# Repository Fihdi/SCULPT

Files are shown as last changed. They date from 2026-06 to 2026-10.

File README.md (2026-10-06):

# 8hp ADSR Module

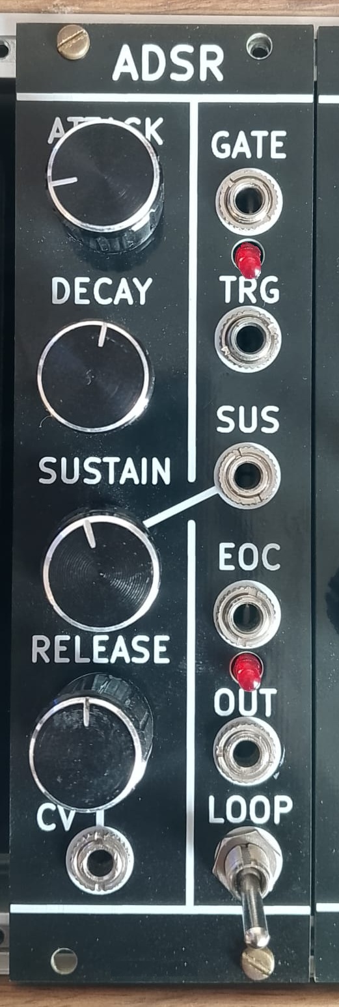
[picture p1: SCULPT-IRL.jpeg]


SCULPT is a 4 stage envelope generator with Attack, Decay, Sustain and Release control. Additionally, the Sustain level and the Release time can be voltage controlled. Engaging the LOOP switch connects the End-of-cycle (EOC) Gate back into the GATE input, turning the module into an LFO with variable rise and fall times.

While the module is in the sustain phase, an external CV source can be used to modulate the sustain level. The DECAY knob changes the slew rate of the SUS input during this stage.

A gate signal to the TRG input sets the module to the attack stage. 

By using a random voltage generator, the EOC output, together with the Release-CV input, can be used to create so-called "Krell patches".

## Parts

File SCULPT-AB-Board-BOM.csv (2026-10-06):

Reference | Value | Footprint | Qty
C1,C3 | 10n | Capacitor_SMD:C_0805_2012Metric | 2
C2,C7,C8 | 1u | Capacitor_SMD:C_0805_2012Metric | 3
C4,C5,C6 | 100n | Capacitor_SMD:C_0805_2012Metric | 3
C9 | ext | Capacitor_THT:C_Radial_D6.3mm_H11.0mm_P2.50mm | 1
D1,D2,D3,D4,D6,D7,D8,D9,D11,D12,D13,D14,D15,D16 | IN4148 | Diode_SMD:D_SOD-323_HandSoldering | 14
D5,D10 | LED | LED_THT:LED_D3.0mm | 2
J4,J5,J6,J7,J8,J9 | AudioJack2 | Library:MonoTRS | 6
J15 | Conn_02x05_Odd_Even | Connector_IDC:IDC-Header_2x05_P2.54mm_Vertical | 1
Q3,Q4,Q5 | BC847 | Package_TO_SOT_SMD:SOT-23 | 3
R1,R4,R16 | 47k | Resistor_SMD:R_0805_2012Metric | 3
R2,R10,R14,R19,R21,R29,R30,R32 | 100k | Resistor_SMD:R_0805_2012Metric | 8
R3,R7,R8,R13,R15,R17,R18,R23,R27 | 10k | Resistor_SMD:R_0805_2012Metric | 9
R5 | 100R | Resistor_SMD:R_0805_2012Metric | 1
R12,R20 | 1k | Resistor_SMD:R_0805_2012Metric | 2
R22 | 33k | Resistor_SMD:R_0805_2012Metric | 1
R24 | 2k2 | Resistor_SMD:R_0805_2012Metric | 1
R25 | 4k7 | Resistor_SMD:R_0805_2012Metric | 1
RV1,RV2,RV3,RV4 | 100k | Potentiometer_THT:Potentiometer_Alpha_RD901F-40-00D_Single_Vertical | 4
SW1 | SW_SPDT | Library:Switch | 1
U1 | TL074 | Package_SO:SOIC-14_3.9x8.7mm_P1.27mm | 1
U2 | TL072 | Package_SO:SOIC-8_3.9x4.9mm_P1.27mm | 1
U4 | 4066 | Package_SO:SOIC-14_3.9x8.7mm_P1.27mm | 1

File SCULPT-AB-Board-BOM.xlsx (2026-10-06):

 |  |  | SCULPT-AB-Board BOM
Item # | *Designator | *Qty | Manufacturer | *Mfg Part # | Description / Value | *Package/Footprint | Type | Your Instructions / Notes
1 | C1,C3 | 2 |  | C1710 | 10n | Capacitor_SMD:C_0805_2012Metric
2 | C2,C7,C8 | 3 |  | C28323 | 1u | Capacitor_SMD:C_0805_2012Metric
3 | C4,C5,C6 | 3 |  | C49678 | 100n | Capacitor_SMD:C_0805_2012Metric
4 | C9 | 1 |  |  | ext | Capacitor_THT:C_Radial_D6.3mm_H11.0mm_P2.50mm |  | DNP
5 | D1,D2,D3,D4,D6,D7,D8,D9,D11,D12,D13,D14,D15,D16 | 14 |  | C917117 | 1N4148 | Diode_SMD:D_SOD-323_HandSoldering
6 | D5,D10 | 2 |  |  | LED | LED_THT:LED_D3.0mm |  | DNP
7 | J4,J5,J6,J7,J8,J9 | 6 |  |  | AudioJack2 | Library:MonoTRS |  | DNP
8 | J15 | 1 |  |  | Conn_02x05_Odd_Even | Connector_IDC:IDC-Header_2x05_P2.54mm_Vertical |  | DNP
9 | Q3,Q4,Q5 | 3 |  | C475630 | BC847 | Package_TO_SOT_SMD:SOT-23
10 | R1,R4,R16 | 3 |  | C2930202 | 47k | Resistor_SMD:R_0805_2012Metric
11 | R2,R10,R14,R19,R21,R29,R30,R32 | 8 |  | C2907217 | 100k | Resistor_SMD:R_0805_2012Metric
12 | R3,R7,R8,R13,R15,R17,R18,R23,R27 | 9 |  | C17414 | 10k | Resistor_SMD:R_0805_2012Metric
13 | R5 | 1 |  | C17408 (https://www.lcsc.com/de/product-detail/C17408.html?s_z=n_q_t_100%2520ohm%25200805) | 100R | Resistor_SMD:R_0805_2012Metric
14 | R12,R20 | 2 |  | C95781 | 1k | Resistor_SMD:R_0805_2012Metric
15 | R22 | 1 |  | C2933415 | 33k | Resistor_SMD:R_0805_2012Metric
16 | R24 | 1 |  | C114561 | 2k2 | Resistor_SMD:R_0805_2012Metric
17 | R25 | 1 |  | C2907326 | 4k7 | Resistor_SMD:R_0805_2012Metric
18 | RV1,RV2,RV3,RV4 | 4 |  |  | 100k | Potentiometer_THT:Potentiometer_Alpha_RD901F-40-00D_Single_Vertical |  | DNP
19 | SW1 | 1 |  |  | SW_SPDT | Library:Switch |  | DNP
20 | U1 | 1 |  | C12594 | TL074 | Package_SO:SOIC-14_3.9x8.7mm_P1.27mm
21 | U2 | 1 |  | C67473 | TL072 | Package_SO:SOIC-8_3.9x4.9mm_P1.27mm
22 | U4 | 1 |  | C54755 | 4066 | Package_SO:SOIC-14_3.9x8.7mm_P1.27mm
Need a quick and accurante quote? Need an efficient production? Please read SMT Ordering Necessary Files & Info in 1 minute. Thank you very much!
Click for Instructions on How to Create a BOM (https://www.pcbway.com/blog/PCB_Assembly/How_to_Build_a_BOM__Bill_Of_Materials_.html)

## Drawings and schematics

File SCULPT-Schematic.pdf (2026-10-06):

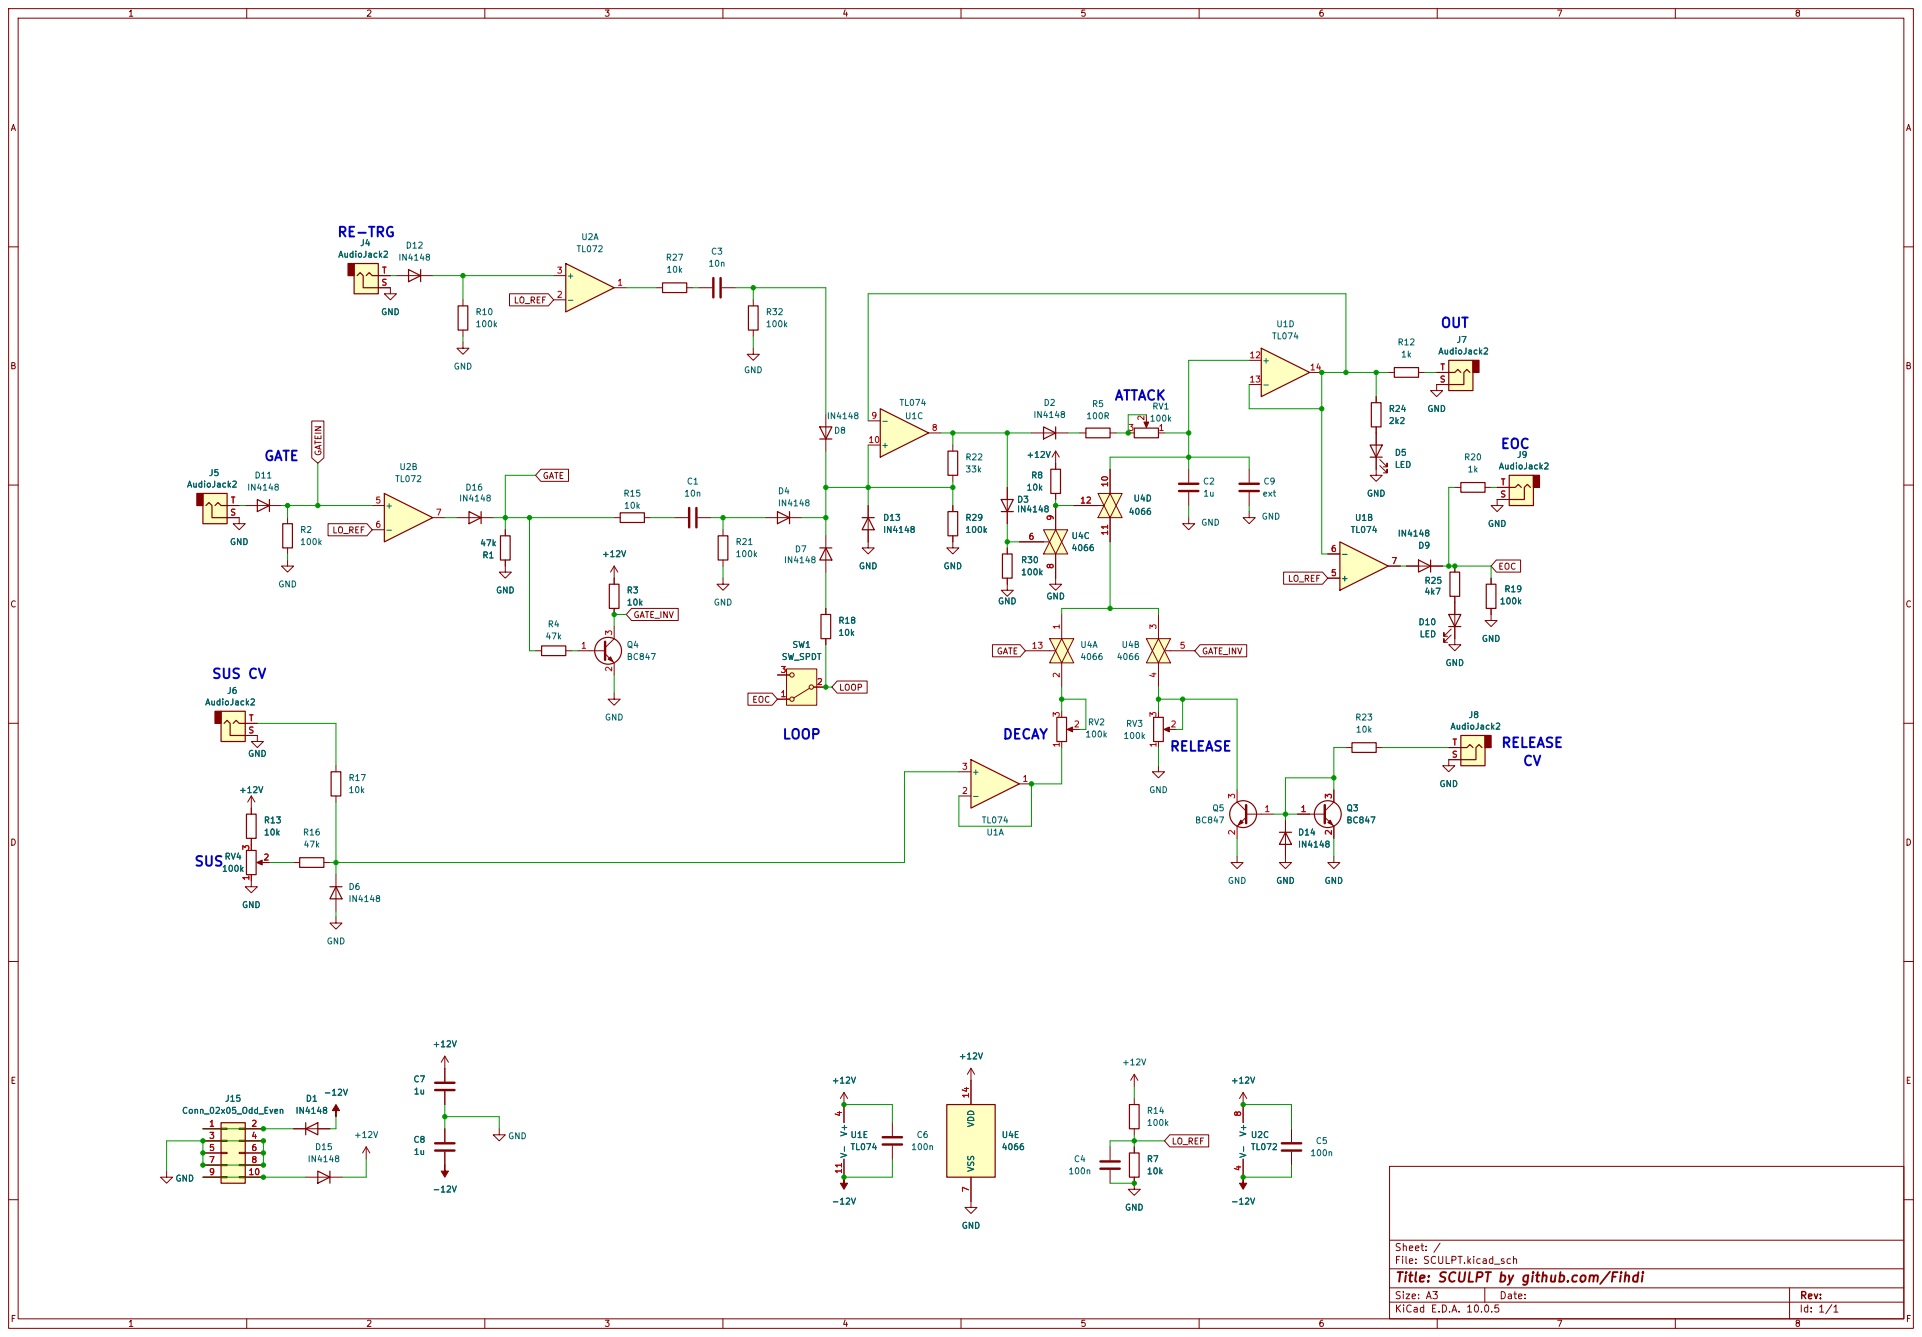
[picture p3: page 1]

5 5 | 6 6
7 7 | 8 8

Sheet: /
File: SCULPT.kicad_sch
Title: SCULPT by github.com/Fihdi

Size: A3 | Rev: | F Date:
KiCad E.D.A. 10.0.5 | Id: 1/1

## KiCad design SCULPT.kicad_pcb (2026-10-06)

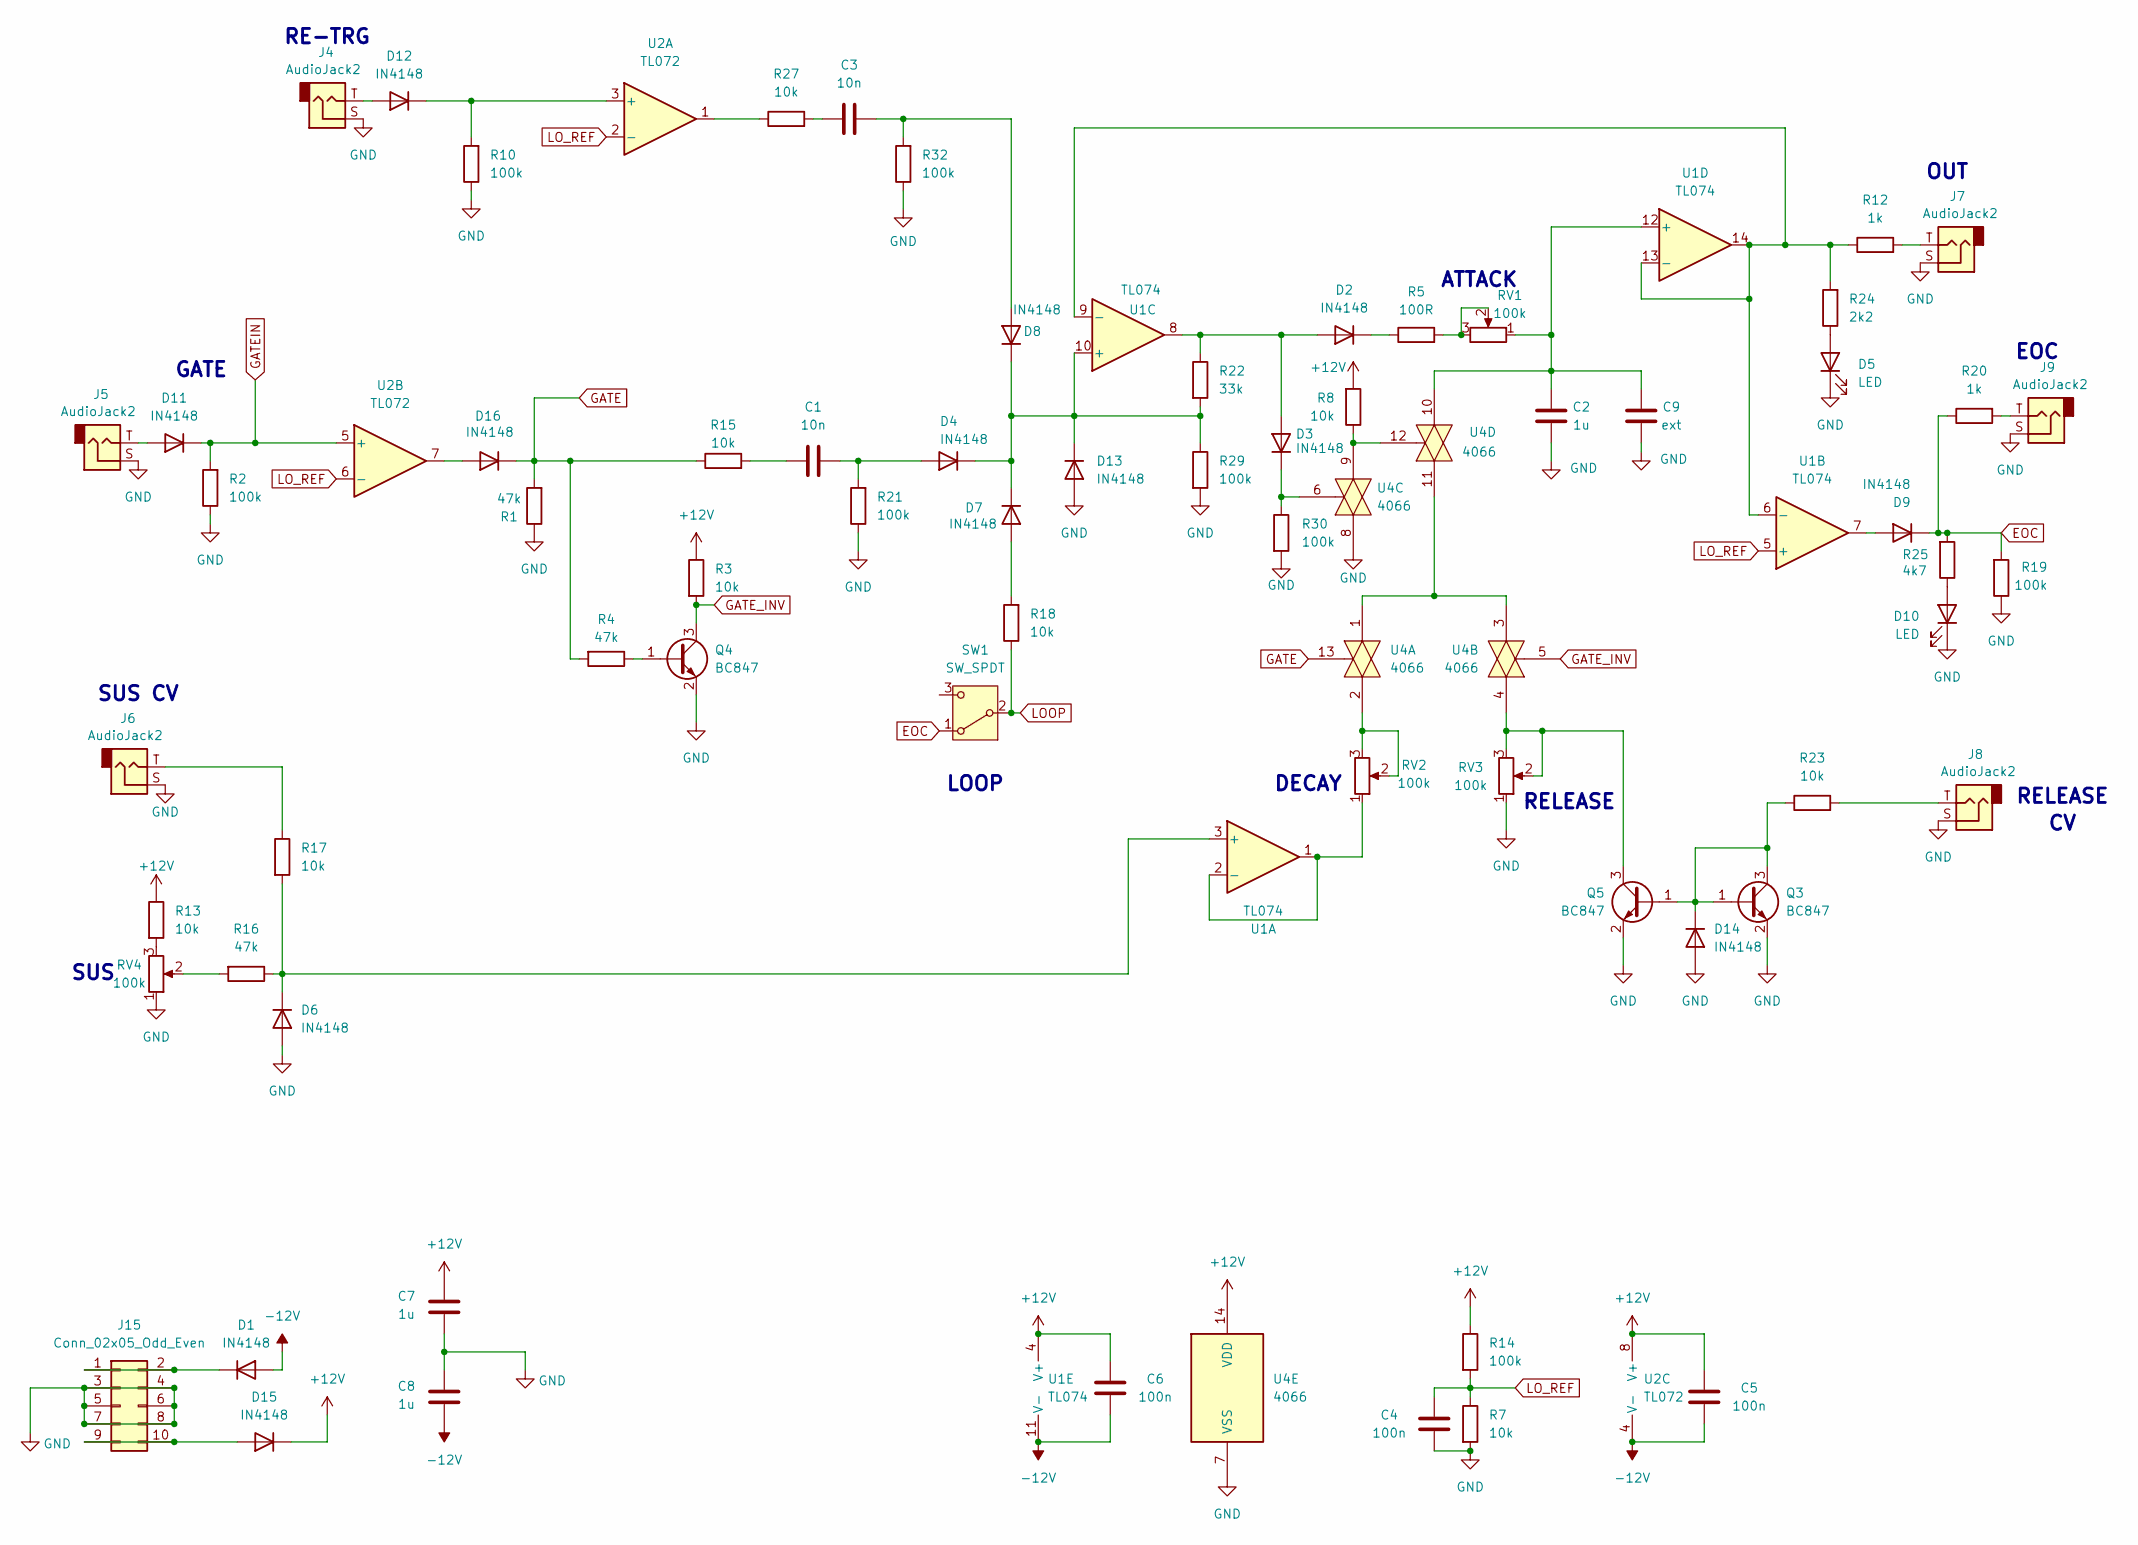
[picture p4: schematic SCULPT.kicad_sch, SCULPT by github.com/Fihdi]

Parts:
C1, C3: 10n; C_0805_2012Metric
C2, C7, C8: 1u; C_0805_2012Metric
C4, C5, C6: 100n; C_0805_2012Metric
C9: ext; C_Radial_D6.3mm_H11.0mm_P2.50mm
D1, D2, D3, D4, D6, D7, D8, D9, D11, D12, D13, D14, D15, D16: IN4148; D_SOD-323_HandSoldering
D5, D10: LED; LED_D3.0mm
J4, J5, J6, J7, J8, J9: AudioJack2; MonoTRS
J15: Conn_02x05_Odd_Even; IDC-Header_2x05_P2.54mm_Vertical
Q3, Q4, Q5: BC847; SOT-23
R1, R4, R16: 47k; R_0805_2012Metric
R2, R10, R14, R19, R21, R29, R30, R32: 100k; R_0805_2012Metric
R3, R7, R8, R13, R15, R17, R18, R23, R27: 10k; R_0805_2012Metric
R5: 100R; R_0805_2012Metric
R12, R20: 1k; R_0805_2012Metric
R22: 33k; R_0805_2012Metric
R24: 2k2; R_0805_2012Metric
R25: 4k7; R_0805_2012Metric
RV1, RV2, RV3, RV4: 100k; Potentiometer_Alpha_RD901F-40-00D_Single_Vertical
SW1: SW_SPDT; Switch
U1: TL074; SOIC-14_3.9x8.7mm_P1.27mm
U2: TL072; SOIC-8_3.9x4.9mm_P1.27mm
U4: 4066; SOIC-14_3.9x8.7mm_P1.27mm

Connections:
+12V: C5.1, C6.1, C7.1, D15.1 (K), R3.1, R8.2, R13.1, R14.1, U1.4 (V+), U2.8 (V+), U4.14 (VDD)
-12V: C5.2, C6.2, C8.2, D1.2 (A), U1.11 (V-), U2.4 (V-)
EOC: D9.1 (K), R19.2, R20.1, R25.2, SW1.1 (A)
GATE: D16.1 (K), R1.2, R4.2, R15.1, U4.13
GATEIN: D11.1 (K), R2.2, U2.5 (+)
GATE_INV: Q4.3 (C), R3.2, U4.5
GND: C2.1, C4.1, C7.2, C8.1, C9.1, D5.1 (K), D6.2 (A), D10.1 (K), D13.2 (A), D14.2 (A), J4.S, J5.S, J6.S, J7.S, J8.S, J9.S, J15.3, J15.4, J15.5, J15.6, J15.7, J15.8, Q3.2 (E), Q4.2 (E), Q5.2 (E), R1.1, R2.1, R7.2, R10.1, R19.1, R21.1, R29.2, R30.2, R32.1, RV3.1, RV4.1, U4.7 (VSS), U4.8
LOOP: R18.1, SW1.2 (B)
LO_REF: C4.2, R7.1, R14.2, U1.5 (+), U2.2 (-), U2.6 (-)
unnamed: C1.1, R15.2
unnamed: C3.1, R27.2
unnamed: D1.1 (K), J15.1, J15.2
unnamed: D2.2 (A), D3.2 (A), R22.1, U1.8
unnamed: D2.1 (K), R5.1
unnamed: D3.1 (K), R30.1, U4.6
unnamed: C1.2, D4.2 (A), R21.2
unnamed: D5.2 (A), R24.1
unnamed: D6.1 (K), R16.1, R17.2, U1.3 (+)
unnamed: D7.2 (A), R18.2
unnamed: C3.2, D8.2 (A), R32.2
unnamed: D9.2 (A), U1.7
unnamed: D10.2 (A), R25.1
unnamed: D11.2 (A), J5.T
unnamed: D12.2 (A), J4.T
unnamed: D12.1 (K), R10.2, U2.3 (+)
unnamed: D4.1 (K), D7.1 (K), D8.1 (K), D13.1 (K), R22.2, R29.1, U1.10 (+)
unnamed: D14.1 (K), Q3.1 (B), Q3.3 (C), Q5.1 (B), R23.1
unnamed: D15.2 (A), J15.9, J15.10
unnamed: D16.2 (A), U2.7
unnamed: J6.T, R17.1
unnamed: J7.T, R12.2
unnamed: J8.T, R23.2
unnamed: J9.T, R20.2
unnamed: Q4.1 (B), R4.1
unnamed: Q5.3 (C), RV3.2, RV3.3, U4.4
unnamed: R5.2, RV1.2, RV1.3
unnamed: R8.1, U4.9, U4.12
unnamed: R13.2, RV4.3
unnamed: R16.2, RV4.2
unnamed: R27.1, U2.1
unnamed: RV2.2, RV2.3, U4.2
unnamed: RV2.1, U1.1, U1.2 (-)
unnamed: R12.1, R24.2, U1.6 (-), U1.9 (-), U1.13 (-), U1.14
unnamed: C2.2, C9.2, RV1.1, U1.12 (+), U4.10
unnamed: U4.1, U4.3, U4.11

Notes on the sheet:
ATTACK
DECAY
LOOP
RELEASE
RE-TRG
SUS
GATE
SUS CV
EOC
OUT

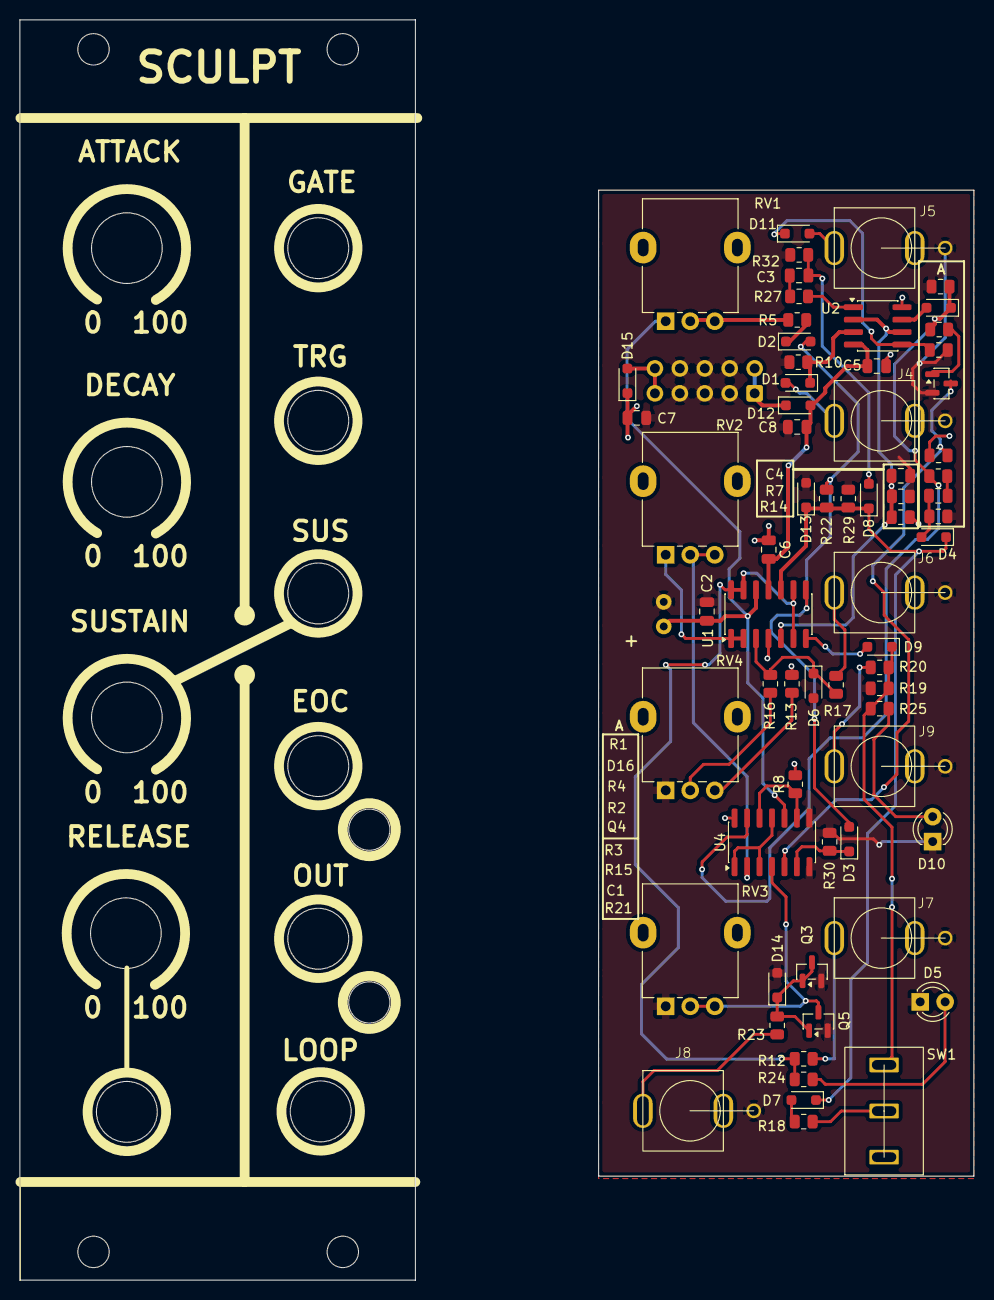
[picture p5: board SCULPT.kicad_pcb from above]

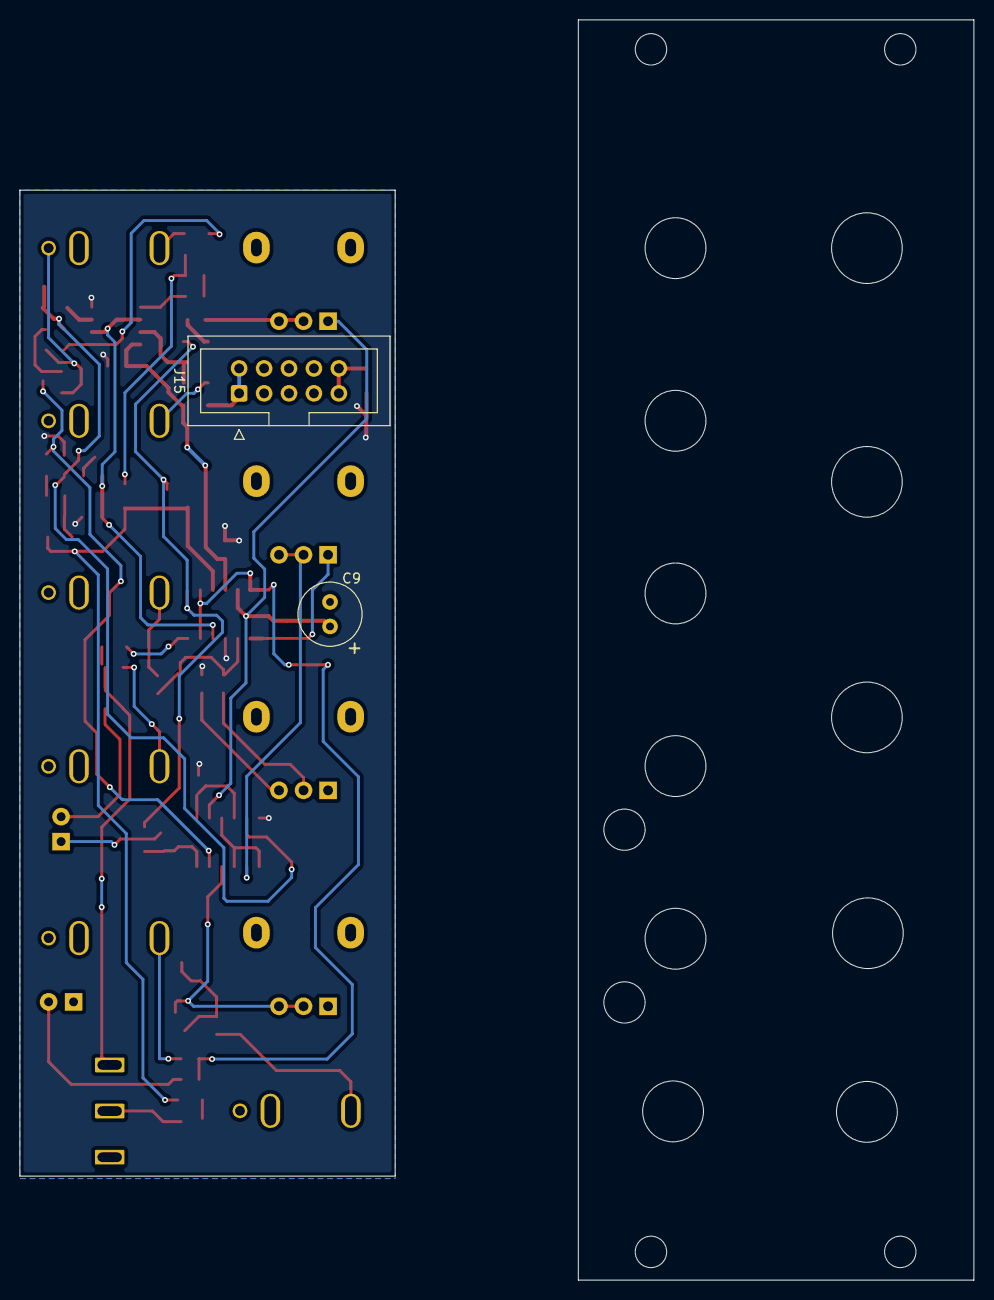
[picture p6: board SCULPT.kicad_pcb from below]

Board: 2 copper layers, 38.2 x 100.5 mm, 69 parts (2 on the bottom side), 45 nets.
